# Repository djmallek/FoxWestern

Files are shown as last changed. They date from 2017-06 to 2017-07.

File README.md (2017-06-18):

# FoxWestern
This is for a rocketry project.  It uses tracking, remote, and onboard logging to keep track of the rocket's location and howmany G's it pulls.
Additionally, functionality is being added for electroincs control over control surfaces for future purposes.
Right now, the board is a general development board, with plans to further refine design as physical rocket tests andcontrol surface research advance.
All physical rocket files are stored on google drive.

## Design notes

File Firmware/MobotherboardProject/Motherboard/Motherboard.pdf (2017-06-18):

## Motherboard Project Configuration Report

# 1. Description

## 1.1. Project

Project Name | Motherboard
Board Name | Motherboard
Generated with: | STM32CubeMX 4.20.1
Date | 06/13/2017

## 1.2. MCU

MCU Series | STM32F4
MCU Line | STM32F411
MCU name | STM32F411RETx
MCU Package | LQFP64
MCU Pin number | 64

# 2. Pinout Configuration

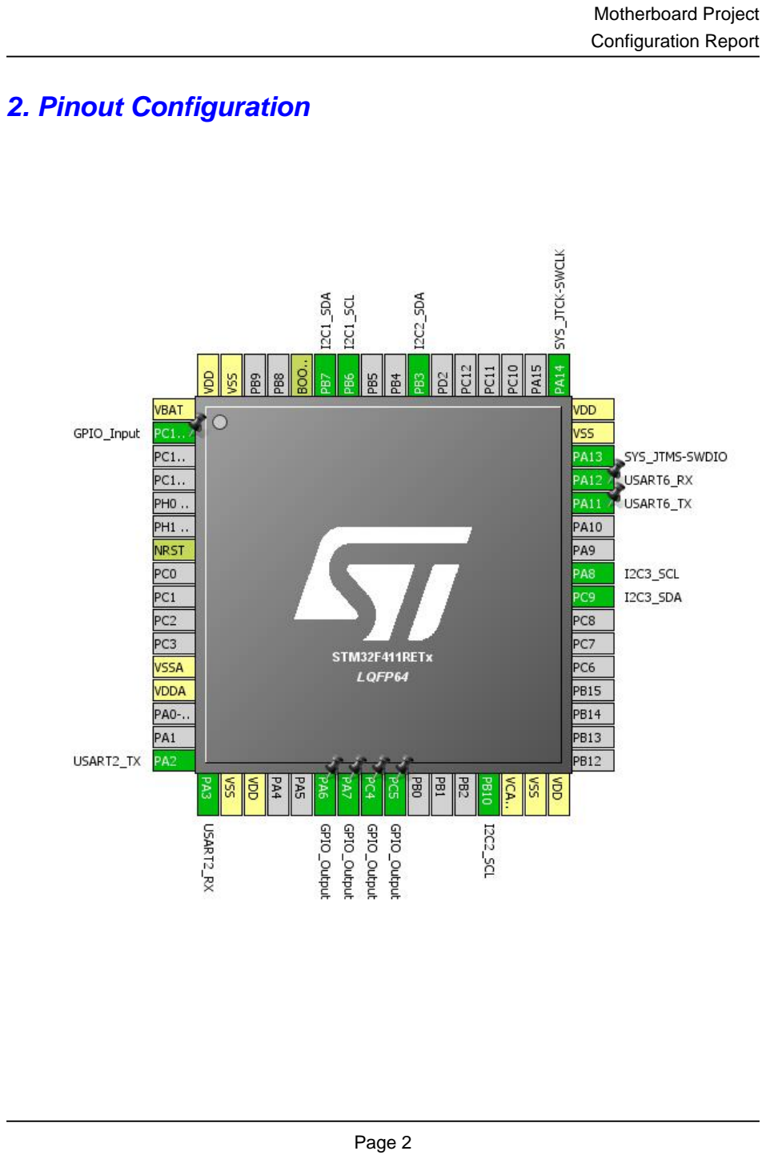
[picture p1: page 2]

# 3. Pins Configuration

Pin Number LQFP64 | Pin Name (function after reset) | Pin Type | Alternate Function(s) | Label
1 | VBAT | Power
2 | PC13-ANTI_TAMP * | I/O | GPIO_Input
7 | NRST | Reset
12 | VSSA | Power
13 | VDDA | Power
16 | PA2 | I/O | USART2_TX
17 | PA3 | I/O | USART2_RX
18 | VSS | Power
19 | VDD | Power
22 | PA6 * | I/O | GPIO_Output
23 | PA7 * | I/O | GPIO_Output
24 | PC4 * | I/O | GPIO_Output
25 | PC5 * | I/O | GPIO_Output
29 | PB10 | I/O | I2C2_SCL
30 | VCAP1 | Power
31 | VSS | Power
32 | VDD | Power
40 | PC9 | I/O | I2C3_SDA
41 | PA8 | I/O | I2C3_SCL
44 | PA11 | I/O | USART6_TX
45 | PA12 | I/O | USART6_RX
46 | PA13 | I/O | SYS_JTMS-SWDIO
47 | VSS | Power
48 | VDD | Power
49 | PA14 | I/O | SYS_JTCK-SWCLK
55 | PB3 | I/O | I2C2_SDA
58 | PB6 | I/O | I2C1_SCL
59 | PB7 | I/O | I2C1_SDA
60 | BOOT0 | Boot
63 | VSS | Power
64 | VDD | Power

## * The pin is affected with an I/O function

# 4. Clock Tree Configuration

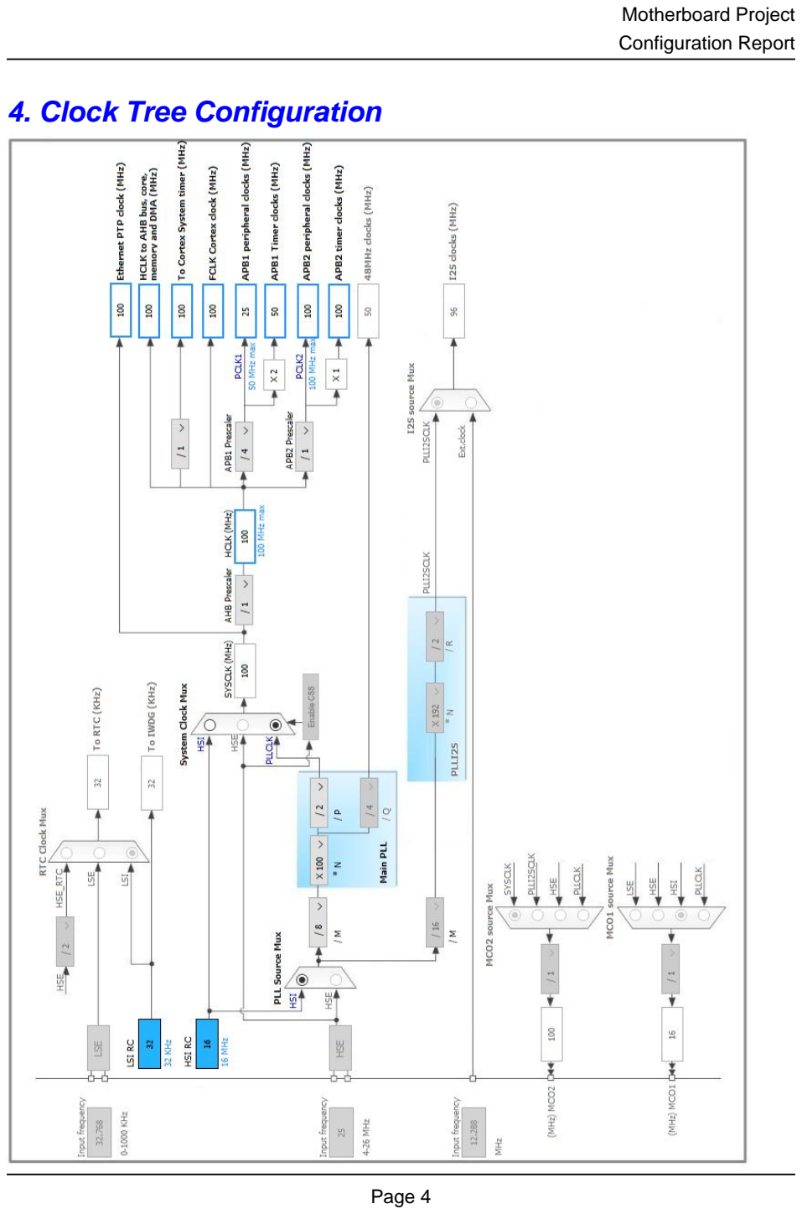
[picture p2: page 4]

# 5. IPs and Middleware Configuration

# 5.1. I2C1

## I2C: I2C

## 5.1.1. Parameter Settings:

### Master Features:

I2C Speed Mode | Standard Mode
I2C Clock Speed (Hz) | 100000

### Slave Features:

Clock No Stretch Mode | Disabled
Primary Address Length selection | 7-bit
Dual Address Acknowledged | Disabled
Primary slave address | 0
General Call address detection | Disabled

# 5.2. I2C2

## I2C: I2C

## 5.2.1. Parameter Settings:

### Master Features:

I2C Speed Mode | Standard Mode
I2C Clock Speed (Hz) | 100000

### Slave Features:

Clock No Stretch Mode | Disabled
Primary Address Length selection | 7-bit
Dual Address Acknowledged | Disabled
Primary slave address | 0
General Call address detection | Disabled

# 5.3. I2C3

## I2C: I2C

## 5.3.1. Parameter Settings:

### Master Features:

I2C Speed Mode | Standard Mode
I2C Clock Speed (Hz) | 100000

### Slave Features:

Clock No Stretch Mode | Disabled
Primary Address Length selection | 7-bit
Dual Address Acknowledged | Disabled
Primary slave address | 0
General Call address detection | Disabled

# 5.4. SYS

## Debug: Serial Wire Timebase Source: SysTick

# 5.5. USART2

## Mode: Asynchronous

## 5.5.1. Parameter Settings:

### Basic Parameters:

Baud Rate | 9600 *
Word Length | 8 Bits (including Parity)
Parity | None
Stop Bits | 1

### Advanced Parameters:

Data Direction | Receive and Transmit
Over Sampling | 16 Samples

# 5.6. USART6

## Mode: Asynchronous

## 5.6.1. Parameter Settings:

### Basic Parameters:

Baud Rate | 9600 *
Word Length | 8 Bits (including Parity)
Parity | None
Stop Bits | 1

### Advanced Parameters:

Data Direction | Receive and Transmit
Over Sampling | 16 Samples

### * User modified value

# 6. System Configuration

# 6.1. GPIO configuration

IP | Pin | Signal | GPIO mode | GPIO pull/up pull down | Max Speed | User Label
I2C1 | PB6 | I2C1_SCL | Alternate Function Open Drain | Pull-up | Very High *
| PB7 | I2C1_SDA | Alternate Function Open Drain | Pull-up | Very High *
I2C2 | PB10 | I2C2_SCL | Alternate Function Open Drain | Pull-up | Very High *
| PB3 | I2C2_SDA | Alternate Function Open Drain | Pull-up | Very High *
I2C3 | PC9 | I2C3_SDA | Alternate Function Open Drain | Pull-up | Very High *
| PA8 | I2C3_SCL | Alternate Function Open Drain | Pull-up | Very High *
SYS | PA13 | SYS_JTMS-SWDIO | n/a | n/a | n/a
| PA14 | SYS_JTCK-SWCLK | n/a | n/a | n/a
USART2 | PA2 | USART2_TX | Alternate Function Push Pull | Pull-up | Very High *
| PA3 | USART2_RX | Alternate Function Push Pull | Pull-up | Very High *
USART6 | PA11 | USART6_TX | Alternate Function Push Pull | Pull-up | Very High *
| PA12 | USART6_RX | Alternate Function Push Pull | Pull-up | Very High *
GPIO | PC13-ANTI_TAMP | GPIO_Input | Input mode | Pull-down * | n/a
| PA6 | GPIO_Output | Output Push Pull | No pull-up and no pull-down | Low
| PA7 | GPIO_Output | Output Push Pull | No pull-up and no pull-down | Low
| PC4 | GPIO_Output | Output Push Pull | No pull-up and no pull-down | Low
| PC5 | GPIO_Output | Output Push Pull | No pull-up and no pull-down | Low

# 6.2. DMA configuration

## nothing configured in DMA service

# 6.3. NVIC configuration

Interrupt Table | Enable | Preenmption Priority | SubPriority
Non maskable interrupt | true | 0 | 0
Hard fault interrupt | true | 0 | 0
Memory management fault | true | 0 | 0
Pre-fetch fault, memory access fault | true | 0 | 0
Undefined instruction or illegal state | true | 0 | 0
System service call via SWI instruction | true | 0 | 0
Debug monitor | true | 0 | 0
Pendable request for system service | true | 0 | 0
System tick timer | true | 0 | 0
PVD interrupt through EXTI line 16 | unused
Flash global interrupt | unused
RCC global interrupt | unused
I2C1 event interrupt | unused
I2C1 error interrupt | unused
I2C2 event interrupt | unused
I2C2 error interrupt | unused
USART2 global interrupt | unused
USART6 global interrupt | unused
I2C3 event interrupt | unused
I2C3 error interrupt | unused
FPU global interrupt | unused

### * User modified value

# 7. Power Consumption Calculator report

### 7.1. Microcontroller Selection

Series | STM32F4
Line | STM32F411
MCU | STM32F411RETx
Datasheet | 026289_Rev4

### 7.2. Parameter Selection

Temperature | 25
Vdd | null

# 8. Software Project

## 8.1. Project Settings

Name | Value
Project Name | Motherboard
Project Folder | C:\Users\djmal\Documents\GitHub\FoxWestern\Firmware\MobotherboardProject\
Toolchain / IDE | SW4STM32
Firmware Package Name and Version | STM32Cube FW_F4 V1.16.0

## 8.2. Code Generation Settings

Name | Value
STM32Cube Firmware Library Package | Copy only the necessary library files
Generate peripheral initialization as a pair of '.c/.h' files | No
Backup previously generated files when re-generating | No
Delete previously generated files when not re-generated | Yes
Set all free pins as analog (to optimize the power consumption) | No

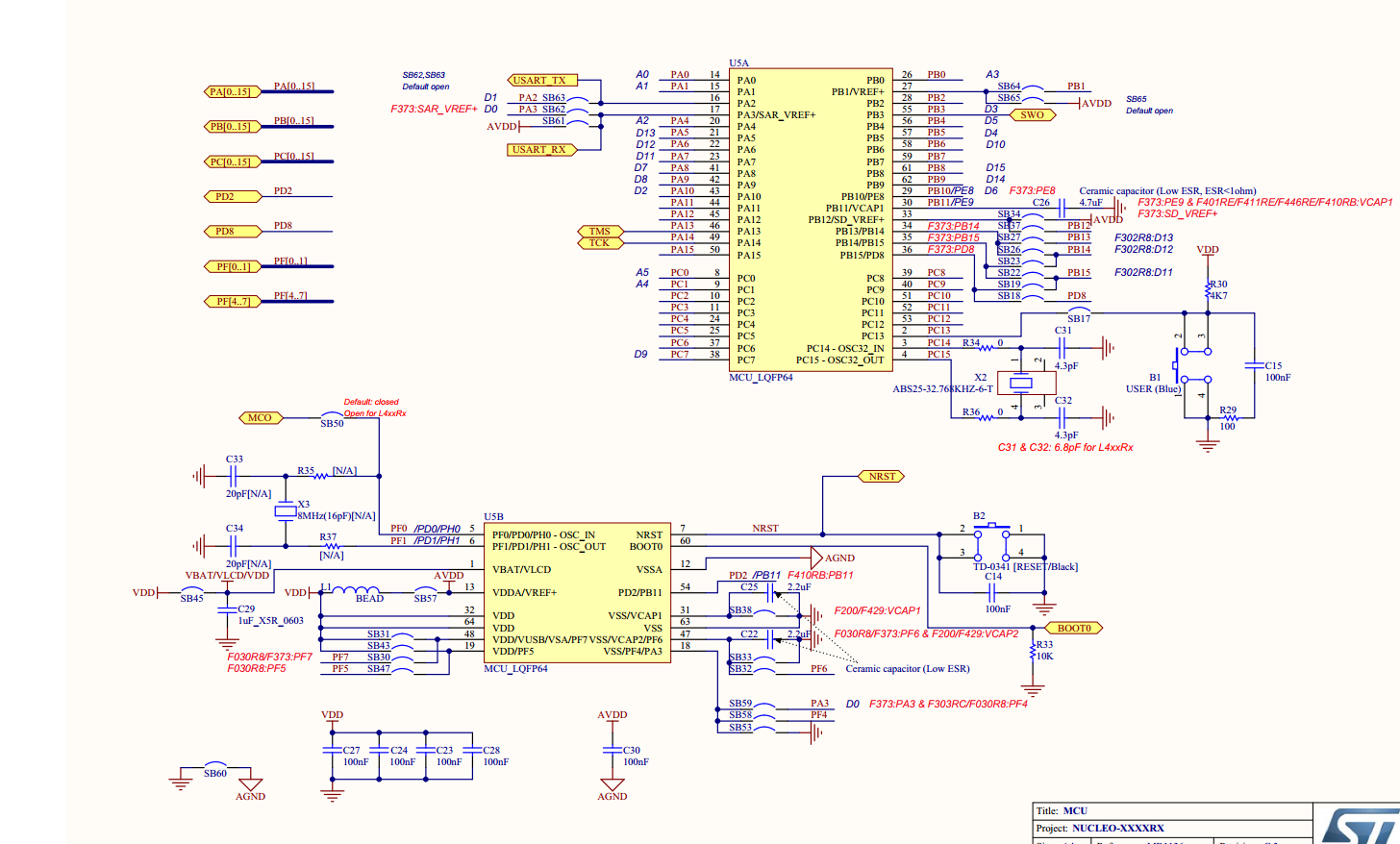
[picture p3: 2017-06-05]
Board1/NucleoSchematic.PNG

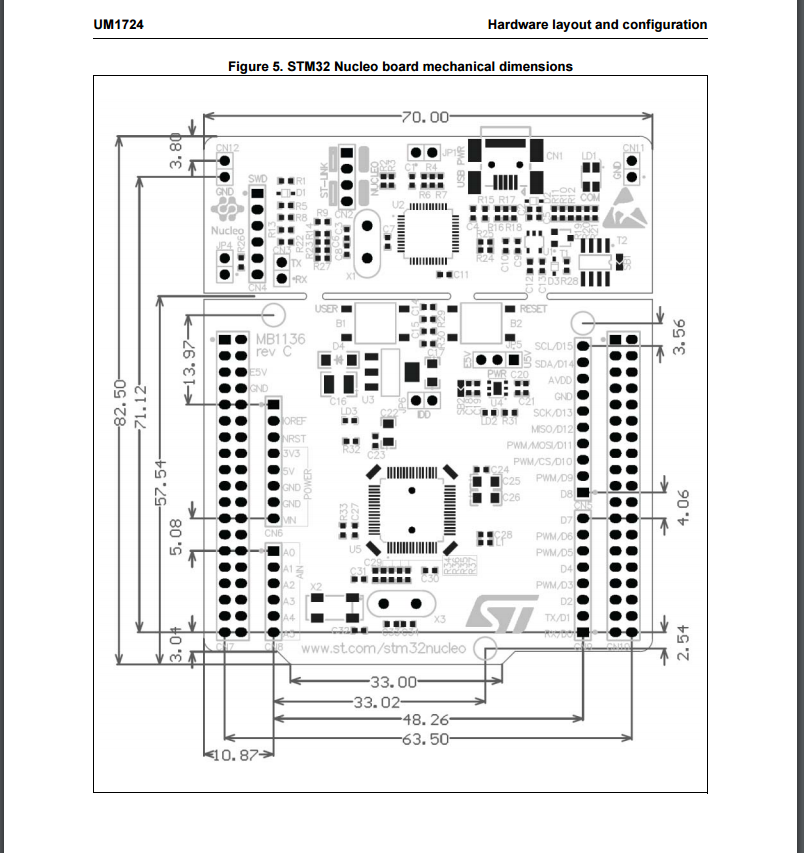
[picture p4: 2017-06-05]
Board1/NucleoSize.PNG

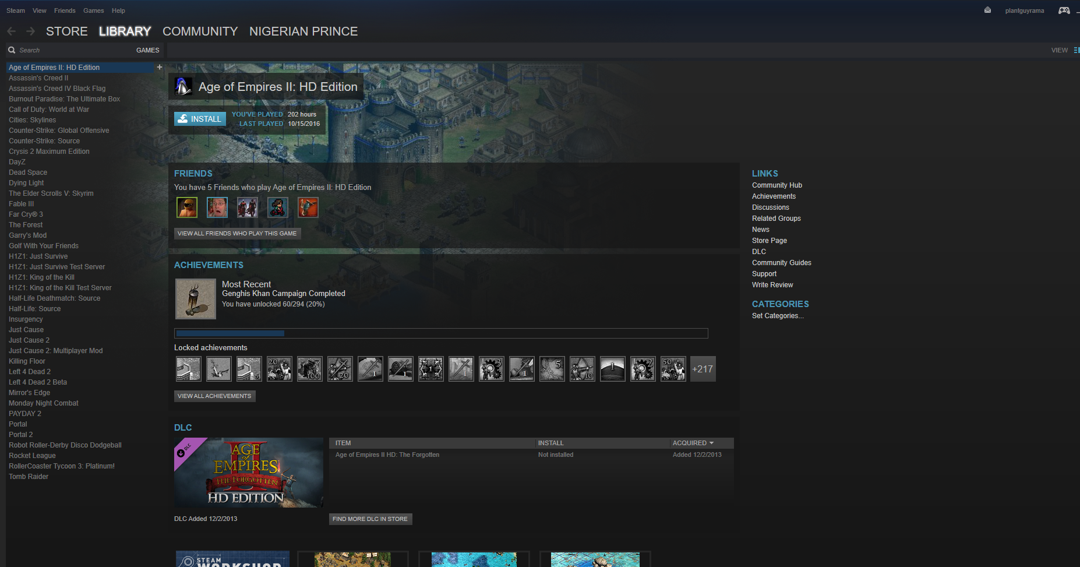
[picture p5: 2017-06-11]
Board1/Capture.PNG

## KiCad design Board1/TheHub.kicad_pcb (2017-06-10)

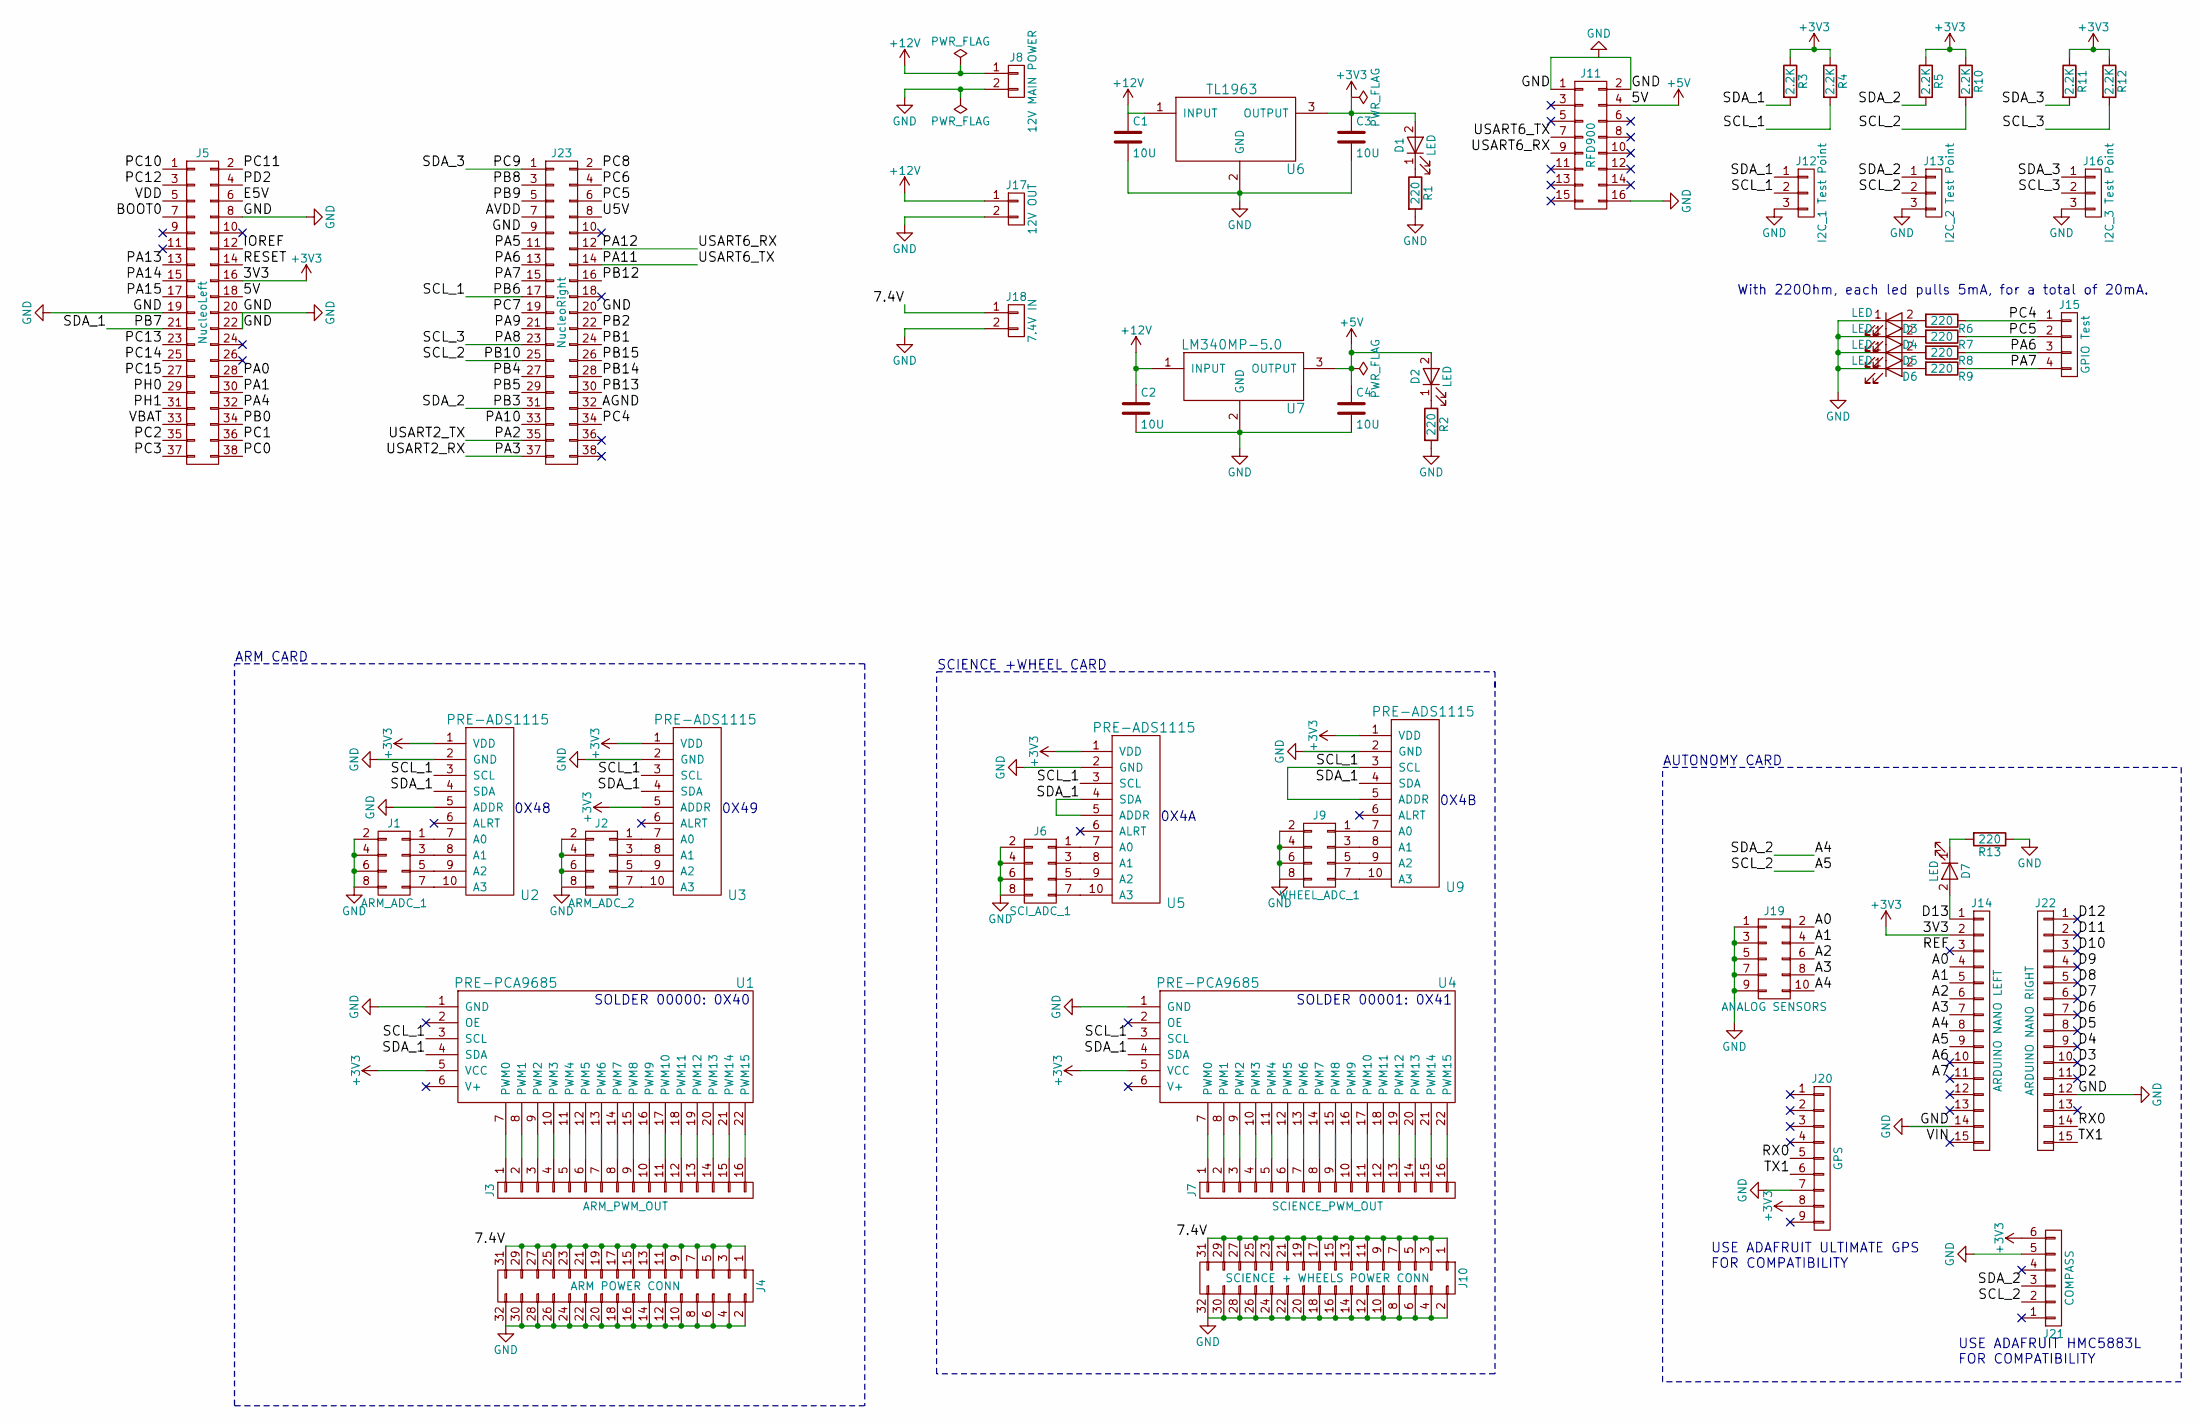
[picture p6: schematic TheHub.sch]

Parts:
C1, C2, C3, C4: 10U; C_0805
D1, D2, D3, D4, D5, D6, D7: LED; LED_0805
J1: ARM_ADC_1; Pin_Header_Straight_2x04_Pitch2.54mm
J2: ARM_ADC_2; Pin_Header_Straight_2x04_Pitch2.54mm
J3: ARM_PWM_OUT; Pin_Header_Straight_1x16_Pitch2.54mm
J4: ARM POWER CONN; Pin_Header_Straight_2x16_Pitch2.54mm
J5: NucleoLeft; Socket_Strip_Straight_2x19_Pitch2.54mm
J6: SCI_ADC_1; Pin_Header_Straight_2x04_Pitch2.54mm
J7: SCIENCE_PWM_OUT; Pin_Header_Straight_1x16_Pitch2.54mm
J8: 12V MAIN POWER; XT60
J9: WHEEL_ADC_1; Pin_Header_Straight_2x04_Pitch2.54mm
J10: SCIENCE + WHEELS POWER CONN; Pin_Header_Straight_2x19_Pitch2.54mm
J11: RFD900; Socket_Strip_Angled_2x08_Pitch2.54mm
J12: I2C_1 Test Point; Pin_Header_Straight_1x03_Pitch2.54mm
J13: I2C_2 Test Point; Pin_Header_Straight_1x03_Pitch2.54mm
J14: ARDUINO NANO LEFT; Socket_Strip_Straight_1x15_Pitch2.54mm
J15: GPIO Test; Pin_Header_Straight_1x04_Pitch2.54mm
J16: I2C_3 Test Point; Pin_Header_Straight_1x03_Pitch2.54mm
J17: 12V OUT; XT60
J18: 7.4V IN; XT60
J19: ANALOG SENSORS; Pin_Header_Straight_2x05_Pitch2.54mm
J20: GPS; Socket_Strip_Straight_1x09_Pitch2.54mm
J21: COMPASS; Socket_Strip_Straight_1x06_Pitch2.54mm
J22: ARDUINO NANO RIGHT; Socket_Strip_Straight_1x15_Pitch2.54mm
J23: NucleoRight; Socket_Strip_Straight_2x19_Pitch2.54mm
R1, R2, R6, R7, R8, R9, R13: 220; R_0805
R3, R4, R5, R10, R11, R12: 2.2K; R_0805
U1, U4: PRE-PCA9685; PCA9685
U2, U3, U5, U9: PRE-ADS1115; Socket_Strip_Straight_1x10_Pitch2.54mm
U6: TL1963; SOT-223-3Lead_TabPin2
U7: LM340MP-5.0; SOT-223-3Lead_TabPin2

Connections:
+3V3: C3.1, D1.2 (A), J5.16, J14.2, J20.8, J21.6, R3.1, R4.1, R5.1, R10.1, R11.1, R12.1, U1.5 (VCC), U2.1 (VDD), U3.1 (VDD), U3.5 (ADDR), U4.5 (VCC), U5.1 (VDD), U6.3 (OUTPUT), U9.1 (VDD)
+5V: C4.1, D2.2 (A), J5.18, J11.4, U7.3 (OUTPUT)
+12V: C1.1, C2.1, J8.1, J17.1, U6.1 (INPUT), U7.1 (INPUT)
/7.4V: J4.1, J4.3, J4.5, J4.7, J4.9, J4.11, J4.13, J4.15, J4.17, J4.19, J4.21, J4.23, J4.25, J4.27, J4.29, J4.31, J10.1, J10.3, J10.5, J10.7, J10.9, J10.11, J10.13, J10.15, J10.17, J10.19, J10.21, J10.23, J10.25, J10.27, J10.29, J10.31, J18.1
/A0: J14.4, J19.2
/A1: J14.5, J19.4
/A2: J14.6, J19.6
/A3: J14.7, J19.8
/A4: J13.1, J14.8, J19.10, J21.3, J23.31, R5.2
/A5: J13.2, J14.9, J21.2, J23.25, R10.2
/A6: J14.10
/A7: J14.11
/AGND: J23.32
/AVDD: J23.7
/BOOT0: J5.7
/D2: J22.11
/D3: J22.10
/D4: J22.9
/D5: J22.8
/D6: J22.7
/D7: J22.6
/D8: J22.5
/D9: J22.4
/D10: J22.3
/D11: J22.2
/D12: J22.1
/D13: D7.2 (A), J14.1
/E5V: J5.6
/IOREF: J5.12
/PA0: J5.28
/PA1: J5.30
/PA2: J23.35
/PA3: J23.37
/PA4: J5.32
/PA5: J23.11
/PA6: J15.3, J23.13, R8.1
/PA7: J15.4, J23.15, R9.1
/PA8: J16.2, J23.23, R12.2
/PA9: J23.21
/PA10: J23.33
/PA11: J11.7, J23.14
/PA12: J11.9, J23.12
/PA13: J5.13
/PA14: J5.15
/PA15: J5.17
/PB0: J5.34
/PB1: J23.24
/PB2: J23.22
/PB4: J23.27
/PB5: J23.29
/PB6: J12.2, J23.17, R4.2, U1.3 (SCL), U2.3 (SCL), U3.3 (SCL), U4.3 (SCL), U5.3 (SCL), U9.3 (SCL), U9.5 (ADDR)
/PB7: J5.21, J12.1, R3.2, U1.4 (SDA), U2.4 (SDA), U3.4 (SDA), U4.4 (SDA), U5.4 (SDA), U5.5 (ADDR), U9.4 (SDA)
/PB8: J23.3
/PB9: J23.5
/PB12: J23.16
/PB13: J23.30
/PB14: J23.28
/PB15: J23.26
/PC0: J5.38
/PC1: J5.36
/PC2: J5.35
/PC3: J5.37
/PC4: J15.1, J23.34, R6.1
/PC5: J15.2, J23.6, R7.1
/PC6: J23.4
/PC7: J23.19
/PC8: J23.2
/PC9: J16.1, J23.1, R11.2
/PC10: J5.1
/PC11: J5.2
/PC12: J5.3
/PC13: J5.23
/PC14: J5.25
/PC15: J5.27
/PD2: J5.4
/PH0: J5.29
/PH1: J5.31
/REF: J14.3
/RESET: J5.14
/RX0: J20.5, J22.14
/TX1: J20.6, J22.15
/U5V: J23.8
/VBAT: J5.33
/VDD: J5.5
/VIN: J14.15
GND: C1.2, C2.2, C3.2, C4.2, D3.1 (K), D4.1 (K), D5.1 (K), D6.1 (K), J1.2, J1.4, J1.6, J1.8, J2.2, J2.4, J2.6, J2.8, J4.2, J4.4, J4.6, J4.8, J4.10, J4.12, J4.14, J4.16, J4.18, J4.20, J4.22, J4.24, J4.26, J4.28, J4.30, J4.32, J5.8, J5.19, J5.20, J5.22, J6.2, J6.4, J6.6, J6.8, J8.2, J9.2, J9.4, J9.6, J9.8, J10.2, J10.4, J10.6, J10.8, J10.10, J10.12, J10.14, J10.16, J10.18, J10.20, J10.22, J10.24, J10.26, J10.28, J10.30, J10.32, J11.1, J11.2, J11.16, J12.3, J13.3, J14.14, J16.3, J17.2, J18.2, J19.1, J19.3, J19.5, J19.7, J19.9, J20.7, J21.5, J22.12, J23.9, J23.20, R1.2, R2.2, R13.1, U1.1 (GND), U2.2 (GND), U2.5 (ADDR), U3.2 (GND), U4.1 (GND), U5.2 (GND), U6.2 (GND), U7.2 (GND), U9.2 (GND)
unnamed: D1.1 (K), R1.1
unnamed: D2.1 (K), R2.1
unnamed: D3.2 (A), R6.2
unnamed: D4.2 (A), R7.2
unnamed: D5.2 (A), R8.2
unnamed: D6.2 (A), R9.2
unnamed: D7.1 (K), R13.2
unnamed: J1.1, U2.7 (A0)
unnamed: J1.3, U2.8 (A1)
unnamed: J1.5, U2.9 (A2)
unnamed: J1.7, U2.10 (A3)
unnamed: J2.1, U3.7 (A0)
unnamed: J2.3, U3.8 (A1)
unnamed: J2.5, U3.9 (A2)
unnamed: J2.7, U3.10 (A3)
unnamed: J3.1, U1.7 (PWM0)
unnamed: J3.2, U1.8 (PWM1)
unnamed: J3.3, U1.9 (PWM2)
unnamed: J3.4, U1.10 (PWM3)
unnamed: J3.5, U1.11 (PWM4)
unnamed: J3.6, U1.12 (PWM5)
unnamed: J3.7, U1.13 (PWM6)
unnamed: J3.8, U1.14 (PWM7)
unnamed: J3.9, U1.15 (PWM8)
unnamed: J3.10, U1.16 (PWM9)
unnamed: J3.11, U1.17 (PWM10)
unnamed: J3.12, U1.18 (PWM11)
unnamed: J3.13, U1.19 (PWM12)
unnamed: J3.14, U1.20 (PWM13)
unnamed: J3.15, U1.21 (PWM14)
unnamed: J3.16, U1.22 (PWM15)
unnamed: J6.1, U5.7 (A0)
unnamed: J6.3, U5.8 (A1)
unnamed: J6.5, U5.9 (A2)
unnamed: J6.7, U5.10 (A3)
unnamed: J7.1, U4.7 (PWM0)
unnamed: J7.2, U4.8 (PWM1)
unnamed: J7.3, U4.9 (PWM2)
unnamed: J7.4, U4.10 (PWM3)
unnamed: J7.5, U4.11 (PWM4)
unnamed: J7.6, U4.12 (PWM5)
unnamed: J7.7, U4.13 (PWM6)
unnamed: J7.8, U4.14 (PWM7)
unnamed: J7.9, U4.15 (PWM8)
unnamed: J7.10, U4.16 (PWM9)
unnamed: J7.11, U4.17 (PWM10)
unnamed: J7.12, U4.18 (PWM11)
unnamed: J7.13, U4.19 (PWM12)
unnamed: J7.14, U4.20 (PWM13)
unnamed: J7.15, U4.21 (PWM14)
unnamed: J7.16, U4.22 (PWM15)
unnamed: J9.1, U9.7 (A0)
unnamed: J9.3, U9.8 (A1)
unnamed: J9.5, U9.9 (A2)
unnamed: J9.7, U9.10 (A3)

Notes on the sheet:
ARM CARD
SCIENCE +WHEEL CARD
AUTONOMY CARD
0X48
0X49
0X4A
0X4B
SOLDER 00000: 0X40
SOLDER 00001: 0X41
With 220Ohm, each led pulls 5mA, for a total of 20mA.
USE ADAFRUIT HMC5883L FOR COMPATIBILITY
USE ADAFRUIT ULTIMATE GPS FOR COMPATIBILITY

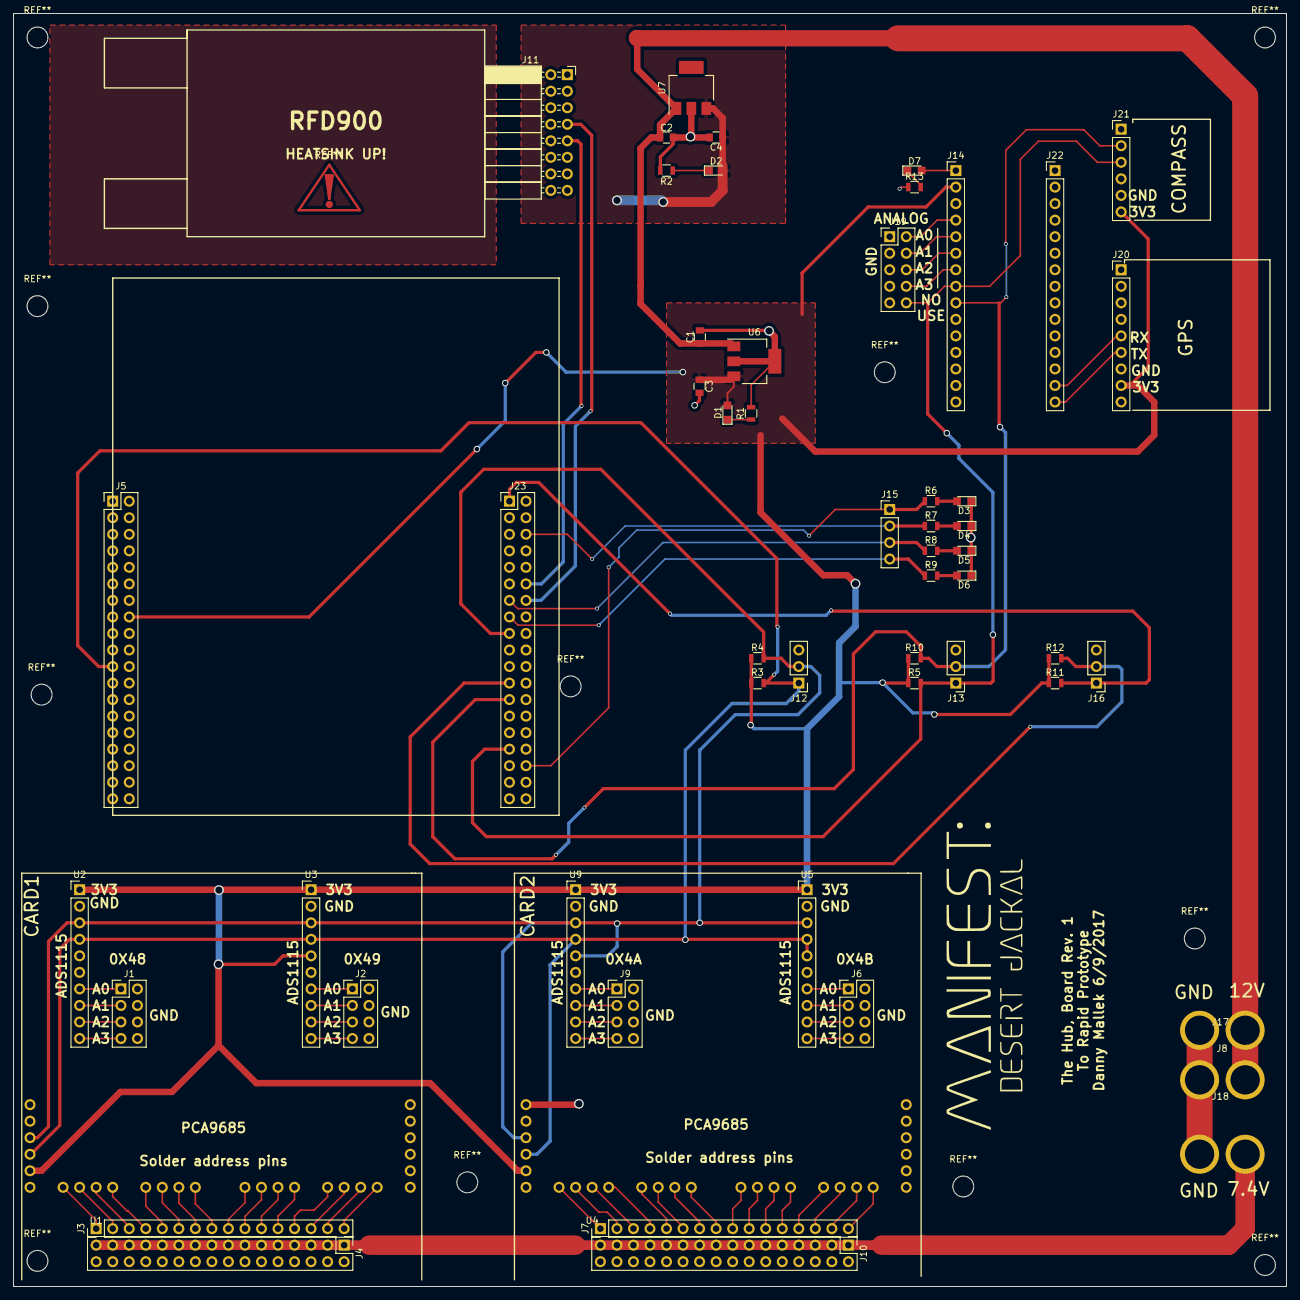
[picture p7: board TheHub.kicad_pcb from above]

Board: 2 copper layers, 195.6 x 195.6 mm, 55 parts (0 on the bottom side), 79 nets.

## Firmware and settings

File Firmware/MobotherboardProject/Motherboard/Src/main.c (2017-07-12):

/**
  ******************************************************************************
  * File Name          : main.c
  * Description        : Main program body
  ******************************************************************************
  *
  * COPYRIGHT(c) 2017 STMicroelectronics
  *
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
  ******************************************************************************
  */
/* Includes ------------------------------------------------------------------*/
#include "main.h"
#include "stm32f4xx_hal.h"

I2C_HandleTypeDef hi2c1;
I2C_HandleTypeDef hi2c2;

UART_HandleTypeDef huart1;
UART_HandleTypeDef huart6;

/* USER CODE BEGIN PV */

/* USER CODE END PV */

void write_8bit_register(uint8_t register_pointer, uint16_t register_value);
void write_16bit_register(uint8_t register_pointer, uint16_t register_value);
void pca9685_init(I2C_HandleTypeDef *hi2c, uint8_t address);
void pca9685_pwm(I2C_HandleTypeDef *hi2c, uint8_t address, uint8_t num, uint16_t on, uint16_t off);
void SystemClock_Config(void);
void Error_Handler(void);
static void MX_GPIO_Init(void);
static void MX_I2C2_Init(void);
static void MX_USART6_UART_Init(void);
static void MX_USART1_UART_Init(void);
static void MX_I2C1_Init(void);

/* USER CODE BEGIN PFP */

/* USER CODE END PFP */

int main(void)
{

  /* MCU Configuration----------------------------------------------------------*/

  /* Reset of all peripherals, Initializes the Flash interface and the Systick. */
  HAL_Init();

  /* Configure the system clock */
  SystemClock_Config();

  /* Initialize all configured peripherals */
  MX_GPIO_Init();
  MX_I2C2_Init();
  MX_USART6_UART_Init();
  MX_USART1_UART_Init();
  MX_I2C1_Init();

  /* USER CODE BEGIN 2 */
  uint8_t Test[] = "Hello World!";
  uint8_t Packet[17];
  uint8_t PWMPacket[50];
  PWMPacket[0] = 0x12;
  PWMPacket[1] = 0x21;
  PWMPacket[2] = 0x45;
  /* USER CODE END 2 */

  /* Infinite loop */
  /* USER CODE BEGIN WHILE */

  write_8bit_register(0x0, 0x0);	//reset PCA9685

  while (1)
  {
	  HAL_UART_Receive(&huart6,Packet,sizeof(Packet),10);
	  //HAL_Delay(20);
	  HAL_UART_Transmit(&huart6,Test,sizeof(Test), 10);
	  HAL_Delay(1);
//	  for(int i=0; i<3; i++){
//		 // HAL_I2C_Master_Transmit(&hi2c1,0x40<<1,PWMPacket[i],sizeof(PWMPacket[i]),10);
//		  HAL_I2C_Master_Transmit(&hi2c1, 0x80, &PWMPacket[i], 1, 1);
//		  //HAL_Delay(0.00001);
//	  }
	  //raw packet -> clean packet by verifying <[size of packet]> or some other checksum library
	  //HAL_GPIO_TogglePin(GPIOA, GPIO_PIN_6);
	  //HAL_Delay(1);
  /* USER CODE END WHILE */
	  pca9685_init(&hi2c1, 0x80);
	  write_8bit_register(0xFE, 0x03);		//set frequency of clock to 200HZ
//	  write_16bit_register(0x42, 500);
//	  write_16bit_register(0x44, 1000);
//	  HAL_Delay(50);
//  /* USER CODE BEGIN 3 */
	   pca9685_pwm(&hi2c1, 0x80, 15, 0, 1024);
	   HAL_Delay(5);



  }
  /* USER CODE END 3 */

}

//void PCA9685_setPrescale(uint8_t prescale){
//	uint8_t oldmode =
//}

void write_8bit_register(uint8_t register_pointer, uint16_t register_value){
    uint8_t data[3];

    data[0] = register_pointer;     // register address
    data[1] = register_value;       // byte of data

    HAL_I2C_Master_Transmit(&hi2c1, 0x40<<1, data, 2, 100);  // data is the start pointer of our array
}

void write_16bit_register(uint8_t register_pointer, uint16_t register_value){
    uint8_t data[3];

    data[0] = register_pointer;     // 0x0C in your example
    data[1] = register_value>>8;    // MSB byte of 16bit data
    data[2] = register_value;       // LSB byte of 16bit data

    HAL_I2C_Master_Transmit(&hi2c1, 0x40<<1, data, 3, 100);  // data is the start pointer of our array
}

void pca9685_init(I2C_HandleTypeDef *hi2c, uint8_t address){
 #define PCA9685_MODE1 0x00
 uint8_t initStruct[2];
 uint8_t prescale = 3; // hardcoded
 HAL_I2C_Master_Transmit(hi2c, address, 0x00, 1, 1);
 uint8_t oldmode = 0; // hardcoded
 // HAL_I2C_Master_Receive(hi2c, address, &oldmode, 1, 1);
 uint8_t newmode = ((oldmode & 0x7F) | 0x10);
 initStruct[0] = PCA9685_MODE1;
 initStruct[1] = newmode;
 HAL_I2C_Master_Transmit(hi2c, address, initStruct, 2, 1);
 initStruct[1] = prescale;
 HAL_I2C_Master_Transmit(hi2c, address, initStruct, 2, 1);
 initStruct[1] = oldmode;
 HAL_I2C_Master_Transmit(hi2c, address, initStruct, 2, 1);
 HAL_Delay(5);
 initStruct[1] = (oldmode | 0xA1);
 HAL_I2C_Master_Transmit(hi2c, address, initStruct, 2, 1);
}

void pca9685_pwm(I2C_HandleTypeDef *hi2c, uint8_t address, uint8_t num, uint16_t on, uint16_t off){
 uint8_t outputBuffer[5] = {0x06 + 4*num, on, (on >> 8), off, (off >> 8)};
 HAL_I2C_Master_Transmit(&hi2c1, address, outputBuffer, 5, 1);
}

/** System Clock Configuration
*/
void SystemClock_Config(void)
{

  RCC_OscInitTypeDef RCC_OscInitStruct;
  RCC_ClkInitTypeDef RCC_ClkInitStruct;

    /**Configure the main internal regulator output voltage 
    */
  __HAL_RCC_PWR_CLK_ENABLE();

  __HAL_PWR_VOLTAGESCALING_CONFIG(PWR_REGULATOR_VOLTAGE_SCALE1);

    /**Initializes the CPU, AHB and APB busses clocks 
    */
  RCC_OscInitStruct.OscillatorType = RCC_OSCILLATORTYPE_HSI;
  RCC_OscInitStruct.HSIState = RCC_HSI_ON;
  RCC_OscInitStruct.HSICalibrationValue = 16;
  RCC_OscInitStruct.PLL.PLLState = RCC_PLL_ON;
  RCC_OscInitStruct.PLL.PLLSource = RCC_PLLSOURCE_HSI;
  RCC_OscInitStruct.PLL.PLLM = 8;
  RCC_OscInitStruct.PLL.PLLN = 100;
  RCC_OscInitStruct.PLL.PLLP = RCC_PLLP_DIV2;
  RCC_OscInitStruct.PLL.PLLQ = 4;
  if (HAL_RCC_OscConfig(&RCC_OscInitStruct) != HAL_OK)
  {
    Error_Handler();
  }

    /**Initializes the CPU, AHB and APB busses clocks 
    */
  RCC_ClkInitStruct.ClockType = RCC_CLOCKTYPE_HCLK|RCC_CLOCKTYPE_SYSCLK
                              |RCC_CLOCKTYPE_PCLK1|RCC_CLOCKTYPE_PCLK2;
  RCC_ClkInitStruct.SYSCLKSource = RCC_SYSCLKSOURCE_PLLCLK;
  RCC_ClkInitStruct.AHBCLKDivider = RCC_SYSCLK_DIV1;
  RCC_ClkInitStruct.APB1CLKDivider = RCC_HCLK_DIV4;
  RCC_ClkInitStruct.APB2CLKDivider = RCC_HCLK_DIV1;

  if (HAL_RCC_ClockConfig(&RCC_ClkInitStruct, FLASH_LATENCY_3) != HAL_OK)
  {
    Error_Handler();
  }

    /**Configure the Systick interrupt time 
    */
  HAL_SYSTICK_Config(HAL_RCC_GetHCLKFreq()/1000);

    /**Configure the Systick 
    */
  HAL_SYSTICK_CLKSourceConfig(SYSTICK_CLKSOURCE_HCLK);

  /* SysTick_IRQn interrupt configuration */
  HAL_NVIC_SetPriority(SysTick_IRQn, 0, 0);
}

/* I2C1 init function */
static void MX_I2C1_Init(void)
{

  hi2c1.Instance = I2C1;
  hi2c1.Init.ClockSpeed = 100000;
  hi2c1.Init.DutyCycle = I2C_DUTYCYCLE_2;
  hi2c1.Init.OwnAddress1 = 0;
  hi2c1.Init.AddressingMode = I2C_ADDRESSINGMODE_7BIT;
  hi2c1.Init.DualAddressMode = I2C_DUALADDRESS_DISABLE;
  hi2c1.Init.OwnAddress2 = 0;
  hi2c1.Init.GeneralCallMode = I2C_GENERALCALL_DISABLE;
  hi2c1.Init.NoStretchMode = I2C_NOSTRETCH_DISABLE;
  if (HAL_I2C_Init(&hi2c1) != HAL_OK)
  {
    Error_Handler();
  }

}

/* I2C2 init function */
static void MX_I2C2_Init(void)
{

  hi2c2.Instance = I2C2;
  hi2c2.Init.ClockSpeed = 100000;
  hi2c2.Init.DutyCycle = I2C_DUTYCYCLE_2;
  hi2c2.Init.OwnAddress1 = 0;
  hi2c2.Init.AddressingMode = I2C_ADDRESSINGMODE_7BIT;
  hi2c2.Init.DualAddressMode = I2C_DUALADDRESS_DISABLE;
  hi2c2.Init.OwnAddress2 = 0;
  hi2c2.Init.GeneralCallMode = I2C_GENERALCALL_DISABLE;
  hi2c2.Init.NoStretchMode = I2C_NOSTRETCH_DISABLE;
  if (HAL_I2C_Init(&hi2c2) != HAL_OK)
  {
    Error_Handler();
  }

}

/* USART1 init function */
static void MX_USART1_UART_Init(void)
{

  huart1.Instance = USART1;
  huart1.Init.BaudRate = 9600;
  huart1.Init.WordLength = UART_WORDLENGTH_8B;
  huart1.Init.StopBits = UART_STOPBITS_1;
  huart1.Init.Parity = UART_PARITY_NONE;
  huart1.Init.Mode = UART_MODE_TX_RX;
  huart1.Init.HwFlowCtl = UART_HWCONTROL_NONE;
  huart1.Init.OverSampling = UART_OVERSAMPLING_16;
  if (HAL_UART_Init(&huart1) != HAL_OK)
  {
    Error_Handler();
  }

}

/* USART6 init function */
static void MX_USART6_UART_Init(void)
{

  huart6.Instance = USART6;
  huart6.Init.BaudRate = 9600;
  huart6.Init.WordLength = UART_WORDLENGTH_8B;
  huart6.Init.StopBits = UART_STOPBITS_1;
  huart6.Init.Parity = UART_PARITY_NONE;
  huart6.Init.Mode = UART_MODE_TX_RX;
  huart6.Init.HwFlowCtl = UART_HWCONTROL_NONE;
  huart6.Init.OverSampling = UART_OVERSAMPLING_16;
  if (HAL_UART_Init(&huart6) != HAL_OK)
  {
    Error_Handler();
  }

}

/** Configure pins as 
        * Analog 
        * Input 
        * Output
        * EVENT_OUT
        * EXTI
*/
static void MX_GPIO_Init(void)
{

  GPIO_InitTypeDef GPIO_InitStruct;

  /* GPIO Ports Clock Enable */
  __HAL_RCC_GPIOC_CLK_ENABLE();
  __HAL_RCC_GPIOH_CLK_ENABLE();
  __HAL_RCC_GPIOA_CLK_ENABLE();
  __HAL_RCC_GPIOB_CLK_ENABLE();

  /*Configure GPIO pin Output Level */
  HAL_GPIO_WritePin(GPIOA, GPIO_PIN_6|GPIO_PIN_7, GPIO_PIN_RESET);

  /*Configure GPIO pin Output Level */
  HAL_GPIO_WritePin(GPIOC, GPIO_PIN_4|GPIO_PIN_5, GPIO_PIN_RESET);

  /*Configure GPIO pin : PC13 */
  GPIO_InitStruct.Pin = GPIO_PIN_13;
  GPIO_InitStruct.Mode = GPIO_MODE_INPUT;
  GPIO_InitStruct.Pull = GPIO_PULLDOWN;
  HAL_GPIO_Init(GPIOC, &GPIO_InitStruct);

  /*Configure GPIO pins : PA6 PA7 */
  GPIO_InitStruct.Pin = GPIO_PIN_6|GPIO_PIN_7;
  GPIO_InitStruct.Mode = GPIO_MODE_OUTPUT_PP;
  GPIO_InitStruct.Pull = GPIO_NOPULL;
  GPIO_InitStruct.Speed = GPIO_SPEED_FREQ_LOW;
  HAL_GPIO_Init(GPIOA, &GPIO_InitStruct);

  /*Configure GPIO pins : PC4 PC5 */
  GPIO_InitStruct.Pin = GPIO_PIN_4|GPIO_PIN_5;
  GPIO_InitStruct.Mode = GPIO_MODE_OUTPUT_PP;
  GPIO_InitStruct.Pull = GPIO_NOPULL;
  GPIO_InitStruct.Speed = GPIO_SPEED_FREQ_LOW;
  HAL_GPIO_Init(GPIOC, &GPIO_InitStruct);

}

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


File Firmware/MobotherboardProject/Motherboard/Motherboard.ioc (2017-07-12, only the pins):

Mcu.UserName=STM32F411RETx
PA10.Signal=USART1_RX
PA11.Signal=USART6_TX
PA12.Signal=USART6_RX
PA13.Signal=SYS_JTMS-SWDIO
PA14.Signal=SYS_JTCK-SWCLK
PA6.Signal=GPIO_Output
PA7.Signal=GPIO_Output
PA9.Signal=USART1_TX
PB10.Signal=I2C2_SCL
PB3.Signal=I2C2_SDA
PB6.Signal=I2C1_SCL
PB7.Signal=I2C1_SDA
PC13-ANTI_TAMP.Signal=GPIO_Input
PC14-OSC32_IN.Signal=RCC_OSC32_IN
PC15-OSC32_OUT.Signal=RCC_OSC32_OUT
PC4.Signal=GPIO_Output
PC5.Signal=GPIO_Output

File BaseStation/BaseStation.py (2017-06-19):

__author__ = 'Danny'

import time
import pygame
import serial

pygame.init()
pygame.joystick.init()
done = False
counter = 0
lastButton = 0

joystickWheels = pygame.joystick.Joystick(0)
joystickWheels.init()
joystickArm = pygame.joystick.Joystick(0)
joystickArm.init()


def getJoyVal(joystick, axis, deadband):
    # type: (object, object) -> object
    "this function returns the value of a joystick, given an axis and a joystick number"
    if abs(joystick.get_axis(axis)) > deadband:
        Value = 255 - (int(round(127 * joystick.get_axis(axis))) + 127)
    else:
        Value = 127
    # map (-1 to 1) to (0.10 to 0.20) for PWM
    # pwm = chr(Value)
    # fpwm = '{:4.4}'.format(pwm)     #for sending direct pwm value
    return Value


def getHat(axis, joystick, number):
    if axis == 'x':
        if str(joystick.get_hat(number))[1] == '1':
            value = 64
        elif str(joystick.get_hat(number))[1] == '-':
            value = 192
        else:
            value = 127
    if axis == 'y':
        if str(joystick.get_hat(number))[4] == '1':
            value = 192
        elif str(joystick.get_hat(number))[4] == '-':
            value = 64
        else:
            value = 127
    return value


def getState(button):
    global counter
    global lastButton
    if (button == 1) and (lastButton == 0):
        lastButton = 1
        state = counter
        counter += 1
        if counter >= 3:
            counter = 0
        return state
    if button == 0:
        lastButton = 0


ser = serial.Serial('COM4', 9600)  # open first serial port
# print ser.portstr       # check which port was really used
# ser.write("<@@@>")      # write a string
# ser.close()





while 1:
    pygame.event.get()
    my_bytes = bytearray()

    # if(joystickArm.get_button(1)):
    #     armActuator

    # if getState == 0:
    my_bytes.append(60)
    my_bytes.append(getJoyVal(joystickWheels, 1, 0.05))  # 1 left wheels
    my_bytes.append(getJoyVal(joystickWheels, 3, 0.05))  # 2 right wheels
    my_bytes.append(getHat('x', joystickWheels, 0))  # 3 cam pan, wheels hat
    my_bytes.append(getHat('y', joystickWheels, 0))  # 4 cam tilt, wheels hat
    if (joystickWheels.get_button(7) == 1):
        my_bytes.append(64)  # 5 cam select, select button
    if (joystickWheels.get_button(7) == 0):
        my_bytes.append(192)  # 5 cam select, select button
    ###########Arm Actuators##########
    if joystickArm.get_button(0) == 1:
        my_bytes.append(getJoyVal(joystickArm, 1, 0.05))  # 6 upper arm speed - axis 3
        my_bytes.append(127)  # 7 lower arm speed
    if joystickArm.get_button(0) == 0:
        my_bytes.append(127)  # 6 upper arm speed - axis 3
        my_bytes.append(255 - getJoyVal(joystickArm, 1, 0.05))  # 7 lower arm speed
    ##################################
    ##########Base Rotation###########
    my_bytes.append(255 - getJoyVal(joystickArm, 0, 0.15))  # 8 base rotation
    ##################################
    ##########Wrist Rotation##########
    if joystickArm.get_button(4) == 1:
        my_bytes.append(30)  # 9 wrist rot - x and y
    elif joystickArm.get_button(5) == 1:
        my_bytes.append(220)
    else:
        my_bytes.append(127)  # 9 wrist rot - x and y
    my_bytes.append(255 - getJoyVal(joystickArm, 4, 0.15))  # 10 wrist yaw - axis 4?
    #################################
    ##########Wrist Pitch###########
    # if(getJoyVal(joystickArm, 3, 0.15) < 45):
    #     my_bytes.append(45)
    # if(getJoyVal(joystickArm, 3, 0.15) >= 170):
    #     my_bytes.append(85)
    # else:
    #     my_bytes.append(255-getJoyVal(joystickArm, 3, 0.05))  # 11 wrist pitch - axis 1
    my_bytes.append(getHat('y', joystickArm, 0))  # 11 wrist pitch - arm hat y
    ###############################
    my_bytes.append(getJoyVal(joystickArm, 2, 0.15))  # 12 wrist claw - axis 2?
    if (joystickArm.get_button(6) == 1):
        my_bytes.append(115)  # 13 soil sensor request
    else:
        my_bytes.append(127)
    my_bytes.append(127)  # 14 gps request
    my_bytes.append(62)

    # bytesToRead = ser.inWaiting()
    # print ser.read(bytesToRead)

    # z = '<'+chr(y1)+chr(y2)+'a'+'>'
    # z = bytes(0x3c)+bytes(0x40)+bytes(0x56)+bytes(0x55)+bytes(0x3E)
    # z=[float(x1),float(y1),float(x2),float(y2)]

    # ser.write(str(z))
    # print getHat('y',joystickWheels,0)
    print(my_bytes)

    ser.write(my_bytes)
    # bytesToRead = ser.inWaiting()
    # print ser.read(bytesToRead)
    time.sleep(.05)

    # ser.close()

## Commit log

2017-06-05 Initial commit, Add nucleo pinout slot, and nucleo resources
    [TheHub.kicad_pcb, TheHub.sch]
2017-06-06 Add PCA9685, ADS1115, and hookups for different parts on i2c bus
    [TheHub.sch]
2017-06-06 Add Pre-PCA9685 footprint
    [TheHub.sch]
2017-06-06 Add STM32Cube files, add basic UART communication eaxample, add HAL references
    [Motherboard.cfg]
2017-06-06 Add support for RFD900 on USART6
    [TheHub.sch]
2017-06-06 Change I2C lines to properly index
    I2C starts at 1, not 0
    [TheHub.sch]
2017-06-06 Add support for I2C123, add test pins for I2C, add 4 GPIO status LEDs with test pins
    [TheHub.sch]
2017-06-06 Add 5v regulator for RFD900, add power status LEDs fro 5v and 3v3
    [TheHub.sch]
2017-06-06 Add additional inputs to autonomy section
    [TheHub.sch]
2017-06-06 Add option for second external regulated voltage, add connections for servo power on wheels, science, and arm cards
    [TheHub.sch]
2017-06-07 Add support for compass on I2C_2, provide prodcut specific guidlines for sensor compatibility
    [TheHub.sch]
2017-06-07 Add XT60 connector, split nano into 2 pieces
    [_saved_TheHub.sch]
2017-06-07 Create cvpcb assiciation, generate netlist
    [TheHub.sch, _saved_TheHub.sch]
2017-06-07 Init PCB layout
    Spread out footprints. TODO: Make changes to nucleo harness
    [_saved_TheHub.sch]
2017-06-09 Change 3v3 regulator, change appropriate pins to sockets
    [TheHub.kicad_pcb, TheHub.sch, _saved_TheHub.sch]
2017-06-09 Create Layout placement forRFD900 and Nucleo
    [TheHub.kicad_pcb]
2017-06-09 Determine Main Board Layout
    [TheHub.kicad_pcb]
2017-06-09 Update nucleo headers to correct pin assignment
    [TheHub.kicad_pcb]
2017-06-09 Finish Layout
    RFD900 Is given insulated copper island to act as a heat spreader
    [TheHub.kicad_pcb]
2017-06-09 Add silkscreen labeling
    [TheHub.kicad_pcb, TheHub.sch]
2017-06-10 Add M3 Mouting Holes
    [TheHub.kicad_pcb]
2017-06-10 Generate Gerbers
    [TheHub-B.Cu.gbl, TheHub-B.Mask.gbs, TheHub-B.SilkS.gbo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]
2017-06-10 Add logo to PCB
    [TheHub.kicad_pcb]
2017-06-19 Add button press functionality
2017-06-19 I2C communication works
2017-07-12 I2C works and is Tested

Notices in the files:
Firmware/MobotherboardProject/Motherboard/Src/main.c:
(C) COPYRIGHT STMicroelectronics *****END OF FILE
